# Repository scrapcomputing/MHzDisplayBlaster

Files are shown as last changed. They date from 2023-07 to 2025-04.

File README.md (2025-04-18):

# MHz Display Blaster

A clone of the TD-37S 2-digit MHz display that was common in 386/486 PC cases.
It can display a Turbo and a non-Turbo number, depending on the state of the Turbo switch.
It also drives the Turbo LED accordingly.

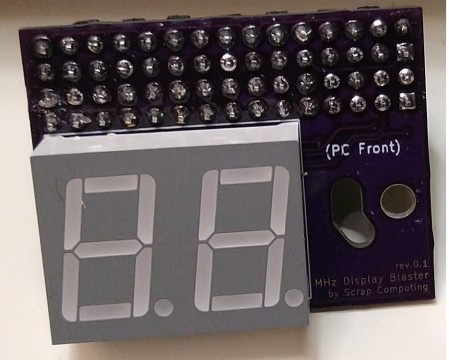
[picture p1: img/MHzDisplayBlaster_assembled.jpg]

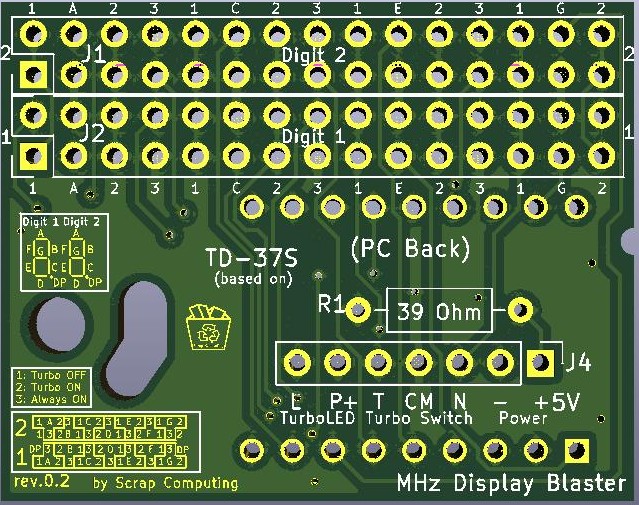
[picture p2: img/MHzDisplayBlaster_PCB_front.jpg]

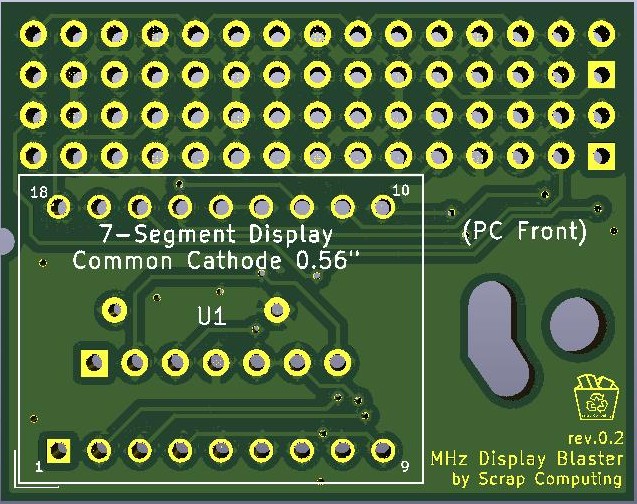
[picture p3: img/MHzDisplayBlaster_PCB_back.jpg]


# Assembly Tips
- Video showing the assembly of rev.0.1 PCB: https://www.youtube.com/watch?v=a4iVehn7APU
> **Warning**
> Please solder the single-row header and the resistor *before* you solder the 7-segment display

# Connecting the board to the PC
- Power: The display is powered by providing 5V to the `+` pin of J4 and GND to the `-` pin.
- Turbo Switch: The turbo switch is a 3-pin 2-way switch. Connect the common wire (middle) to `CM`, the Turbo-ON wire to `T` and the Turbo-OFF wire to `N` (J4).
- Turbo LED: The turbo LED is connected to `L` and `P` on J4. `P` is the positive.

# Display Configuration
- Each segment of the 7-segment display is configured individually with a jumper
- Each segment corresponds to a pin in the configuration headers
- You can short that pin with one of the neighboring state pins (forming a `T` shape) to set its state, which can be one of the following:
  1. ON when Turbo switch is OFF (jumper to position 1)
  2. ON when Turbo switch is ON (jumper to position 2)
  3. Always ON (jumper to position 3)
  4. Always OFF (no jumper)

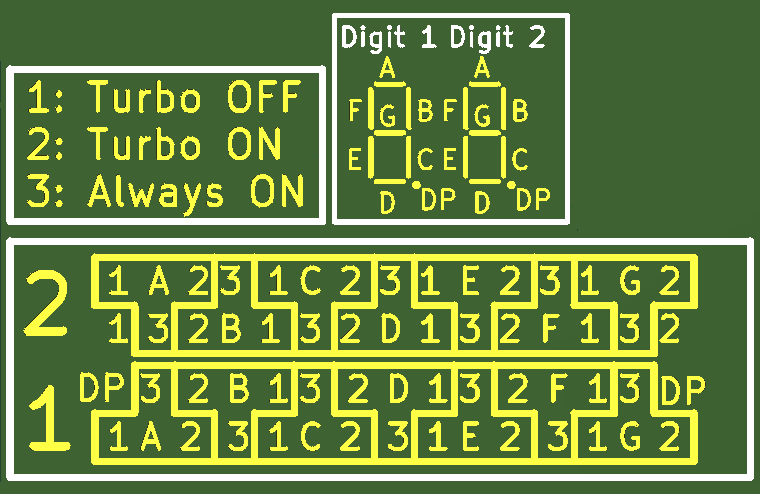
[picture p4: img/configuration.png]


> **Note**
> Please note that the PCB is often mounted up side down on the case.

- For a simple tutorial on how to set it up please refer to the video: https://www.youtube.com/watch?v=wNkg-e47Ex8
- [More resources on MHz Displays](https://www.minuszerodegrees.net/led_speed_display/led_speed_display.htm)

# Bill of materials

Gerber files are published in the releases: https://github.com/scrapcomputing/MHzDisplayBlaster/releases

Reference      | Quantity| Value    | Footprint/Comments
---------------|---------|----------|----------
U1             | 1       |(e.g., LTD-6440G) | 18-DIP (0.600", 15.24mm distance between top and bottom row pins) 2-Digit 7-Segment Display Common Cathode 0.56" Green
J1 J2          | 2       |Conn_02x15| Connector Male PinHeader 2x15 P2.54mm Vertical
J4             | 1       |Conn_01x07| Connector Male PinHeader 1x07 P2.54mm Vertical
R1             | 1       | >= 39 Ohm (100 Ohms recommended)| 1/4 Watt resistor. The original TD37S has a 39 Ohm resistor. But the resistor value is specific to the type of the LEDs used. The original ones operate at around 2V, so the resistor drops 3V. Higher resistor values make the display more dim, but are also better for the longevity of the LEDs in the display.
Jumpers        | 15      |          | 2.54mm pitch jumpers

# Changelist
- Rev.0.2 : Fixes polarity issue, improves info
- Rev.0.1 : Initial revision

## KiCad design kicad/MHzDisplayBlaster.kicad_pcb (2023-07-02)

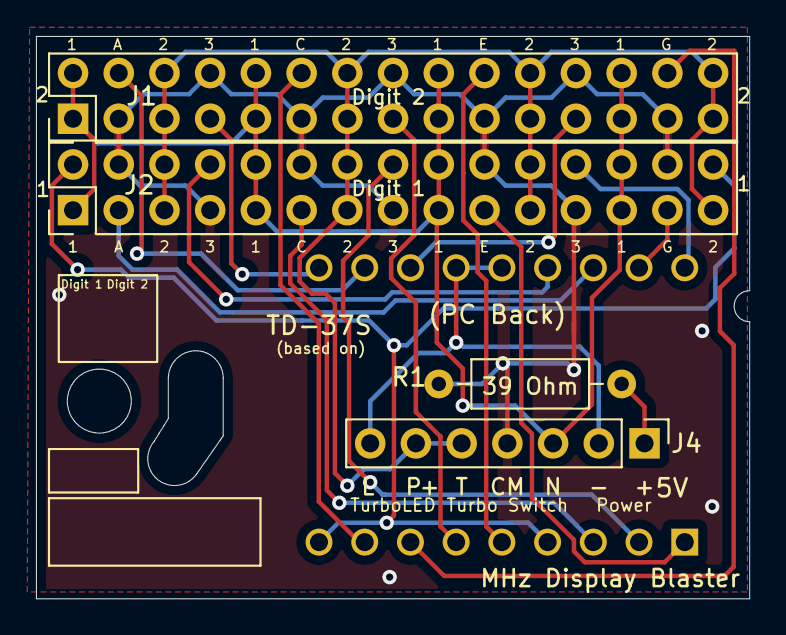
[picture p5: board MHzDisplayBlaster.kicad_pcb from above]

Board: 2 copper layers, 39.6 x 31.2 mm, 5 parts (1 on the bottom side), 20 nets.

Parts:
J1: Conn_02x15 DigitRHS; PinHeader_2x15_P2.54mm_Vertical
J2: Conn_02x15 DigitLHS; PinHeader_2x15_P2.54mm_Vertical
J4: Conn_01x07; PinHeader_1x07_P2.54mm_Vertical
R1: 39 Ohm; R_Axial_DIN0207_L6.3mm_D2.5mm_P10.16mm_Horizontal
U1: DC56-11GWA; DA56-11CGKWA

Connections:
1: J1.1, J1.2, J1.9, J1.10, J1.17, J1.18, J1.25, J1.26, J2.1, J2.9, J2.10, J2.17, J2.18, J2.25, J2.26, J4.3
2: J1.5, J1.6, J1.13, J1.14, J1.21, J1.22, J1.29, J1.30, J2.5, J2.6, J2.13, J2.14, J2.21, J2.22, J2.29, J4.5, J4.6
3: J1.3, J1.8, J1.11, J1.16, J1.19, J1.24, J1.27, J2.4, J2.7, J2.12, J2.15, J2.20, J2.23, J2.28, J4.4, R1.1
DIG1_A: J2.3, U1.16
DIG1_B: J2.8, U1.15
DIG1_C: J2.11, U1.3
DIG1_CC: J4.2, J4.7, U1.13, U1.14
DIG1_D: J2.16, U1.2
DIG1_E: J2.19, U1.1
DIG1_F: J2.24, U1.18
DIG1_G: J2.27, U1.17
DIG2_A: J1.4, U1.11
DIG2_B: J1.7, U1.10
DIG2_C: J1.12, U1.8
DIG2_D: J1.15, U1.6
DIG2_E: J1.20, U1.5
DIG2_F: J1.23, U1.12
DIG2_G: J1.28, U1.7
DP: J2.2, J2.30, U1.4, U1.9
unnamed: J4.1, R1.2

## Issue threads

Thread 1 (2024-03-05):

Resistor Question

oXL0C0Xo, 2024-03-05:
I noticed that the resistor is not listed in the BOM. I can asee that it is a 39 Ohm resistor. Do you think that I could use a 1/8 w resistor, or should this be 1/4 w? I have a bunch of 1/8 w, but if it need to be 1/4 w I will have to order those. Thanks for all of your interesting projects!

scrapcomputing, 2024-03-06:
Thank you for reaching out. Yes, it was missing, I just added it in.
Well, the original display had a 1/4 watt 39 Ohm resistor. The green LEDs operate at ~2V so the resistor needs to drop 3V. So its power consumption is V^2/R which is 9/39 = 0.23 watts . So yes the right value is 1/4 Watt.

However, a 39 Ohm resistor is quite low and the display looks *very* bright, and this can't be good for them in the long term. I would much rather use a 100 Ohm resistor instead, which btw looks plenty bright. For a 100 Ohm resistor 1/8 W is plenty.

Closed 2024-03-13.

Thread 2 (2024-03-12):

2 pin turbo switch?

oXL0C0Xo, 2024-03-12:
Hey there! I'm curious if there is a hack or something that I could do to get this to work with a 2 pin turbo switch, instead of having to replace the turbo switch in my case with a 3-pin? Or is the only way that this will work is if I have a 3-pin turbo switch?

scrapcomputing, 2024-03-13:
If you use a 2-pin switch then the best option would be to get the display to print a frequency value when Turbo is ON and nothing when turbo is OFF.
Alternatively you could use some electronics to implement a 3-pin switch, but replacing the switch would probably be a lot easier.

Closed 2024-03-18.

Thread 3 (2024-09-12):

Redesign Questions

skadarnold, 2024-09-12:
Hello! Thank you for all of your awesome contributions.

I am in the process of making some redesigns of the MhzDisplayBlaster to fit a particular baby AT case that I have. It is my first time working with KiCad with this extent and I figured it would be a good project to become more familiar with how to use it. I was hoping I could get some insight about a few things.

Here is a photo of the example display I am trying to redesign.
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

Everything is front based except for a 3 pin connector on the back that interfaces with the case for power and connection to the turbo button.

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

It seems the pinout is as follows
( IN ) -> Black Ground
( + ) -> Red 5v
( - ) -> White Turbo Button

This is what I have on the schematic so far.
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
I plan on reducing the 7 pin to a 4 pin and adding the 3 pin to the back similar to the original display. I am just unsure where to best connect the turbo button ( - ) wire for proper function.

I still have a long ways to go on the PCB design and I need to double check all of the position and spacing of things, but this is what I have put together so far. I am a little worried that the trace routing might be a little too busy with this layout so please let me know if you have any suggestions.

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

I appreciate all the help in advance!

scrapcomputing, 2024-09-13:
Thanks for reaching out, it is really cool that you are building a reproduction of this display!

I don't own a case with such a display. Is this a logic chip on the left hand side?

The easiest way would be to use the MHzDisplayBlaster schematic and just use a new PCB layout that matches the dimensions and hole locations of your display. This would make sure that the circuit is correct and you would just have to worry  about the routing of the wires.

But if you have reverse engineered the circuit of the display it would be nice to build an exact replica too :D

skadarnold, 2024-09-13:
Actually yes! This schematic and PCB is just a redesign of the MHzDisplayBlaster, though I have really just started. I thought it would be much easier than trying to reverse engineer the original one. I was also curious about the logic chip on the original as well and thought it was a pretty complicated design for what it is. One of the segments of the first digit is broken on the original so I tried to see if I could fix it. There are a group of resistors underneath the display that you can only get to by removing the display entirely. After I removed it, I also learned that the display traces do not connect to the traces on the back on the PCB, and instead are connected to the pads next to the resistors underneath the display. So you have to melt solder down the pins and through the through-holes and hope that they make the right contact. Very strange design so I thought I would give a shot at rearranging the MHzDisplayBlaster instead.

I already have made an original MHzDisplayBlaster as well, but found that it wouldn't quite work with my case. But I have been super excited that you have created this as an option in general.

So in regards to my question above, the snapshot of the schematic is from your original 7 pin connector. I am going to make it into a 4 pin connector and separate power and ground to the 3 pin connector to the back to fit in the case like the original. But in the schematic you have TurboSwOn, TurboSwCM, and TurboSwOff. It might not be clear from my description or photos, but I am trying to figure out which on of those my turbo switch should connect to. I am sort of thinking TurboSwOff might be the most appropriate, but I thought I would try to get some more perspective of how those three pins relate to each other.

Thanks!

scrapcomputing, 2024-09-13:
So in your case there are only 3 cables coming in to the display: 5V, Ground and Turbo.

The turbo switch in the MHzDisplayBlaster's schematic is a 3-pin 2-way switch connecting TurboSwCM to either TurboSwON or TurboSwOff. To get the same functionality with a simple 2-pin on/off switch you would need a different schematic. There is a way to get it to work using a chip like the 7406 (as on your display) and one additional resistor, but I would need to know where the other pin of the Turbo switch is connected to. Is it 5V so when the turbo switch is pressed you get 5V on the white cable, and if it's not pressed you are getting 0V ?

skadarnold, 2024-09-13:
Ah ok this makes a lot more sense and why I was a bit confused. I opened the case up and did a little probing. It seems that when the turbo button is not engaged, it is sending 1.62v through the white Turbo wire. When the Turbo button is engaged, the white wire is reading 0v.

I have also created a fork and committed my initial changes to branch Gecco if you ever feel like to taking a look.

scrapcomputing, 2024-09-14:
1.62V is a strange value.

(i) Is this the voltage when the display is connected ? Could you measure it with the display disconnected?
(ii) Are the LEDs red? Because 1.6V is suspiciously close to the voltage drop of red LEDs if I am not mistaken.

Nice, I will take a look at your branch.

skadarnold, 2024-09-14:
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

You totally nailed it. This is the voltage with the display connected and the LEDs are red. When measuring the white cable while it is disconnected it reads 0v with the Turbo button pressed and depressed.

On the topic of red LEDs I was thinking of using this display instead of the green.
https://www.mouser.com/ProductDetail/859-LTD-6940HR
It seems to match in general, but will this red display work with the MHzDisplayBlaster in it's current design or will it require some modification?

scrapcomputing, 2024-09-14:
Hmm I still don't understand how the white wire works. So the white wire should be connected to one pin of the power turbo button. Is the other pin of the turbo button connected to ground ? But if this is the case there should be some resistor in between otherwise you wouldn't be getting 1.62V.

Regarding the LTD-6940 display, I think it is compatible. It is a common cathode 0.56" display and the pinout looks identical to the LTD-6440G that I used.

skadarnold, 2024-09-14:
Thanks for your patience while I figure this out. I pulled the LED / Button panel off of the case to see if I get a better look at what is going on.

Here is a photo of the button from the inside.
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

So I pulled the multimeter out to check continuity and this is what I figured out.

White <--> Black -> Display Board
White <--> Blue -> Turbo Sw on MB (which is actually not present)

When the button is pressed it is bridging White to Black / Ground and would simultaneously be bridging the Turbo Sw pins on the MB if it were present.

How this relates to the function of the display I am not really sure because the display is configured as it was when I picked it up from a craigslist ad. It should have had a 386 / 486 in it originally, but the original owners had upgraded to a socket 7 Pentium at some point. Pressing the turbo switch currently does not change anything on the display. It would however be nice to have it functioning and at some point I will probably use it with your throttle blaster design.

scrapcomputing, 2024-09-14:
OK so white and blue connect to the motherboard to notify it that it should be in turbo mode and get shorted when you press the turbo button.

Same for white and black, but these connect to the display. And you have already checked that black is ground. But if this is the case then you should not be getting 1.6V on the white cable when the turbo button is pressed, you should be getting 0V shouldn't you? This is what I am confused about.

By the way the turbo switch should probably be a 2-way switch, meaning that the middle pin connects to either side depending on whether the switch is pressed or not, so you could use it with the current design as a backup plan.

skadarnold, 2024-09-14:
So the 1.6v is present on white when the turbo button is not pressed. So I guess this voltage is sort of floating when it is not connected to ground? I am not exactly sure why this is but I can try probing around a little more on the display board to see what is happening.
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
skadarnold, 2024-10-31:
Sorry for the delay on this! I had decided to place a production order as it is currently just to make sure I could test the placement of the cutouts and display before trying to make any finalized changes. It arrived today, and without soldering anything together yet it looks pretty good. I ordered extra components for everything so that I could build and test to make sure the routing and everything electronically works correctly. If it all is exact then great! But this way I have another chance to make a few little tweaks before commiting a final release and pushing it to the main repo.

A couple of notes so far. You are correct that the silk screen was not high enough resolution to display the graphic, so I will need to find a place on the masking, probably on the backside to display that information. There is also some random silk screen text that I missed that is randomly above J2 that I missed. Otherwise, I am feeling quite happy with how the holes and alignment turned out so far. I think it is going to be exactly where I need it.

Components should be arriving tomorrow so I can see if the overall design is correct. I will be in touch, probably over the weekend!

skadarnold, 2024-11-02:
Here is the update after building and testing!

Overall, everything went very well. I was quite impressed with how well the alignment turned out for mounting and the display orientation with the front panel display. There are a couple of things need a bit of revision that didn't work as planned.

1. Turbo button had no affect when configured to position 1 or 2. I double checked the routing and the diagram and the jumpers should have been set correctly. I even tried doing it in correctly just to see if it would help but the segment would only display when using position 3 on each of them. What is strange however if that the Turbo LED light connected to the module seemed to work as expected with the switch, so it seems that the 7404 is working as intended. I will be double checking my routing between the pins, but let me know if you see anything that is out of place. One thing I wasn't sure about is that both lines 2 and 3 from the 7404 make a full loop all the way around and back to the beginning. Maybe this is incorrect?

2. The Turbo LED is much dimmer than the other LEDs, or dim in comparison to the brightness when it is connected directly into the motherboard. When connected to the motherboard it is getting close to a steady 5v, or around 4.9v. When connected to the MHz Display it is closer to 3.7v (I didn't note this down). I will probably start with considering a resistor with less ohms, but I am wondering if the resistor is necessary at all? Maybe only something very small like a 10 - 30 ohm just to help prevent any ringing?

3. For the main input / power connector I ordered some friction lock pin headers that I like to use when the orientation of the connector is important. This connector seems to work well with the button connector built with the chassis. [Molex 3-pin Friction Lock](https://www.mouser.com/ProductDetail/538-22-11-2036) is the component if you are interested. The footprint for this was a bit larger to fit correctly with the resistor right above it, so I will need to adjust this slightly if I want to use it. This should be a small change overall I think.

Otherwise, I am quite pleased with the results for this prototype and will start making any necessary changes for the next production run.

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

Note: I used an extra green display instead of the red for prototyping. I will be using red for the final build.

scrapcomputing, 2024-11-03:
It looks great!

1. Hmm this is interesting. When the Turbo button is pressed "1" should be at 0V and "2" at 5V. When Turbo is not pressed they should switch, 5V and
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

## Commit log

2023-06-20 Rev.0.1: Initial release
    [MHzDisplayBlaster.kicad_pcb, MHzDisplayBlaster.sch]
2023-07-02 Rev.0.2: Fixes polarity issue, improves printed info
    [MHzDisplayBlaster.kicad_pcb, MHzDisplayBlaster.sch]
2024-03-06 Adds resistor to the BOM
2025-04-18 README: Fix BOM connector 1x07
